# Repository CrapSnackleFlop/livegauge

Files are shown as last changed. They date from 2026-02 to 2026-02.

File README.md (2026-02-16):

# livegauge
This project turns a normal 5V analog voltmeter into a dynamic display that can be used to show any stat. It is set up to display the temperature using a DHT11 module running on an esp32. Use it to display Temperature, humidity, wire it to your PC and have it show GPU / CPU usage. Use api to call weather or stock prices, etc. Make it display ALL of these things and give it a button to swap between them on the fly! The possibilites are endless! Wowza!

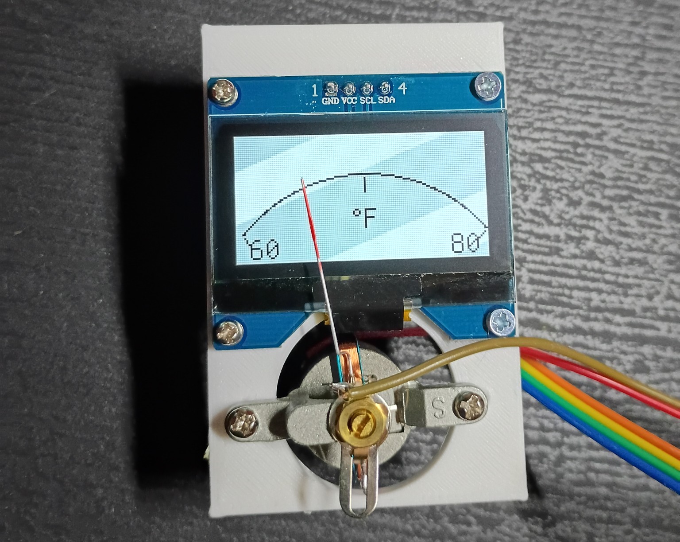
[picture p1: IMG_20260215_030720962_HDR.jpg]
LiveGauge prototype


## parts
- ESP32 (any microcontroller with I2C and PWM)
- Analog voltmeter (mine was 5V but I don't think it matters since we remove resistor from back)
- 1.54" 128x64 I2C OLED display
- DHT11 temperature sensor
- Jumper wires

## wiring
- OLED SDA -- ESP32 pin 21
- OLED SCL -- ESP32 pin 22
- OLED VCC -- 3.3V
- OLED GND -- GND
- DHT11 data -- pin 2
- DHT11 VCC -- 5V
- DHT11 GND -- GND
- analog meter + -- pin 4
- analog meter - -- GND 

## notes
- The code isn't pretty but it works.
- The semicircle drawing and needle calibration was made specific to my meter. My 3d print was offcenter / not perfect so there are comments on the code section for tweaking the arc as well as calibrating the needle.
- For mounting everything on the 3d printed plate, I reused the screws from the analog voltmeter.
- Right now it includes a function to change the value range depending on what the needle is displaying.

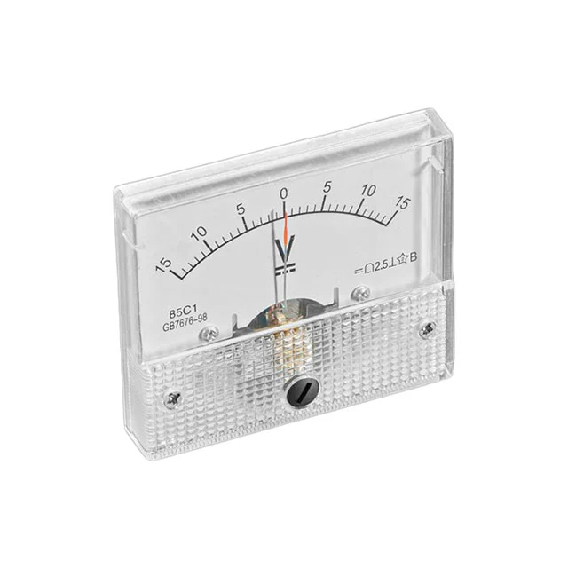
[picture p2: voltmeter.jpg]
Analog Voltmeter


## 3d printing
[View 3D Model](lg_mounting_plate.stl)

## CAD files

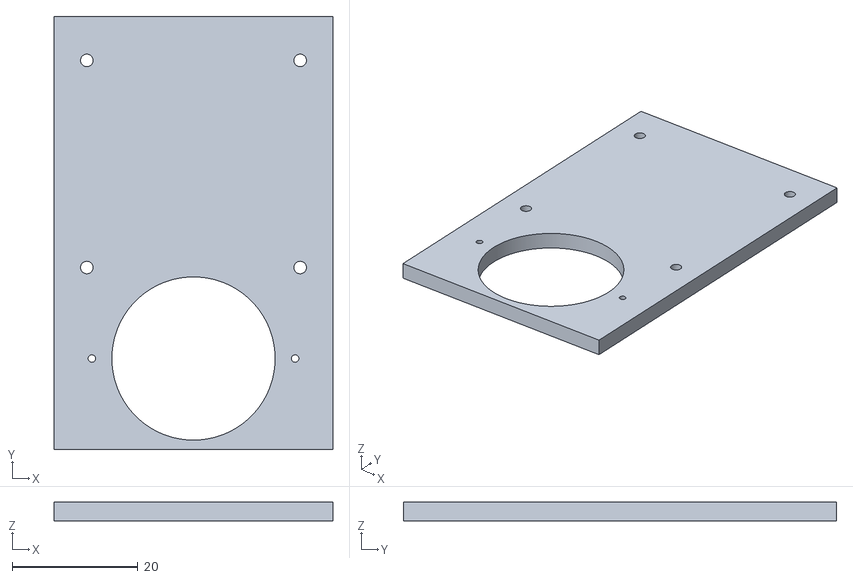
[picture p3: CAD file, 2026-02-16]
lg_mounting_plate.stl
44.4 x 69.0 x 3.00

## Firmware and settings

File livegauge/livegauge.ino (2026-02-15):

#include <Arduino.h>
#include <U8g2lib.h>
#include "DHT.h"
#ifdef U8X8_HAVE_HW_SPI
#include <SPI.h>
#include <Wire.h>
#endif

#define DHTPIN 2
#define DHTTYPE DHT11

U8G2_SH1106_128X64_NONAME_F_SW_I2C u8g2(U8G2_R0, SCL, SDA, U8X8_PIN_NONE);
DHT dht(DHTPIN, DHTTYPE);


// delcare global variables
float temp = 0;
int change = 0;
float ratio = 0;
float pwm =0;

//serial monitor debug on 9600 baud
void setup(void) {
  u8g2.begin();
  Serial.begin(9600);
  drawBackground();
  dht.begin();
}

//clears screen and draws white background with black arc and tik marks
// I think my needle is offcenter or crooked. tweak these values to get it looking right
void drawBackground(){
  u8g2.clearBuffer();
  u8g2.setDrawColor(1);
  u8g2.drawBox(0,0,128,64);
  u8g2.setDrawColor(0);
  u8g2.drawArc(63, 100, 80, 28, 100);
  u8g2.drawLine(2, 51, 8, 60);
  u8g2.drawLine(124, 51, 116, 60);
  u8g2.drawLine(63, 22, 63, 29);
  u8g2.sendBuffer();
}

// draws F functions draw the degrees farenheit in the middle as well as the right and left values
// right now it's set to 0-100 but you can edit the range to display however far you want
void drawF80_100(){
  u8g2.setDrawColor(0);
  u8g2.setFont(u8g2_font_unifont_t_symbols);
  u8g2.drawGlyph(55,48, 176);
  u8g2.drawStr(62,48,"F");
  u8g2.drawStr(4, 62, "80");
  u8g2.drawStr(100,62, "100");
  u8g2.sendBuffer();
}
void drawF60_80(){
  u8g2.setDrawColor(0);
  u8g2.setFont(u8g2_font_unifont_t_symbols);
  u8g2.drawGlyph(55,48, 176);
  u8g2.drawStr(62,48,"F");
  u8g2.drawStr(4, 62, "60");
  u8g2.drawStr(106,62, "80");
  u8g2.sendBuffer();
}
void drawF40_60(){
  u8g2.setDrawColor(0);
  u8g2.setFont(u8g2_font_unifont_t_symbols);
  u8g2.drawGlyph(55,48, 176);
  u8g2.drawStr(62,48,"F");
  u8g2.drawStr(4, 62, "40");
  u8g2.drawStr(106,62, "60");
  u8g2.sendBuffer();
}
void drawF20_40(){
  u8g2.setDrawColor(0);
  u8g2.setFont(u8g2_font_unifont_t_symbols);
  u8g2.drawGlyph(55,48, 176);
  u8g2.drawStr(62,48,"F");
  u8g2.drawStr(4, 62, "20");
  u8g2.drawStr(106,62, "40");
  u8g2.sendBuffer();
}
void drawF0_20(){
  u8g2.setDrawColor(0);
  u8g2.setFont(u8g2_font_unifont_t_symbols);
  u8g2.drawGlyph(55,48, 176);
  u8g2.drawStr(62,48,"F");
  u8g2.drawStr(4, 62, "0");
  u8g2.drawStr(106,62, "20");
  u8g2.sendBuffer();
}

//function to decide what temp values to display
//uses change variable to determine if screen needs to be redrawn
void displayTemp(){
  if (temp >=80 and temp <= 100){
    if(change != 0){
      change = 0;
      drawBackground();
    }
    drawF80_100();
  }
  if (temp >=60 and temp < 80){
    if(change != 1){
      change = 1;
      drawBackground();
    }
    drawF60_80();
  }
  if (temp >=40 and temp < 60){
    if(change != 2){
      change = 2;
      drawBackground();
    }
    drawF40_60();
  }
  if (temp >=20 and temp < 40){
    if(change != 3){
      change = 3;
      drawBackground();
    }
    drawF20_40();
  }
  if (temp >=0 and temp < 20){
    if(change != 4){
      change = 4;
      drawBackground();
    }
    drawF0_20();
  }
}

// ------------NEEDLE CALIBRATION IN THIS SHIT----------------
//function to calculate needle value from temp
// calculates ratio which is the percentage of the needle. 1.00 is full
void temp2Needle(){
  // with no resistor, pwm values for my needle is 8.5=0%, 17 = 50%, 23.5 =100%
  if (change == 0){
    ratio = ((float)temp - 80.0)/20.0;
  }
  if (change == 1){
    ratio = ((float)temp - 60.0)/20.0;
  }
  if (change == 2){
    ratio = ((float)temp - 40.0)/20.0;
  }
  if (change == 3){
    ratio = ((float)temp - 20.0)/20.0;
  }
  if (change == 4){
    ratio = (float)temp/20.0;
  }
  int intRatio = 100 * ratio;
  if (intRatio >= 50){
    pwm = map(intRatio, 50, 95, 17, 23.5); // to calibrate your needle change the last 2 numbers in this section- change 17 to your 50% pwm value and 23.5 to your 100%pwm value
  }
  if (intRatio < 50){
    pwm = map(intRatio, 0, 50, 8.5, 17); // change 8.5 to your 0% pwm value and 17 to your 50% pwm value
  }
  analogWrite(4,pwm); // positive side of the needle on GPIO4

}


void loop(void) {
  temp = dht.readTemperature(true);
    if (isnan(temp)) {
    Serial.println(F("Failed to read from DHT sensor!"));
    return;
  }
  displayTemp();
  temp2Needle();
  Serial.println(change);
  Serial.println(temp);
  Serial.println(ratio);
  Serial.println(pwm);
  Serial.println("-----");
  delay(1000); // updates every second. my dht module hates anything faster
}

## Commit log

2026-02-15 Refactor comments and improve needle calibration logic
2026-02-15 Update README with project details and instructions
    Added parts list, wiring instructions, and notes for the livegauge project.
2026-02-15 fix typo
    Updated the README to clarify semicircle drawing and needle calibration specifics.
2026-02-16 Add prototype image to README
    Added an image of the LiveGauge prototype to the README.
2026-02-16 Change prototype image in README
    Updated the prototype image in the README.
2026-02-16 Fix image path for LiveGauge prototype
    Updated image path for LiveGauge prototype in README.
2026-02-16 Update README with additional notes on code and mounting
    Added notes about code functionality and adjustments.
2026-02-16 Add 3D printing section and model link to README
